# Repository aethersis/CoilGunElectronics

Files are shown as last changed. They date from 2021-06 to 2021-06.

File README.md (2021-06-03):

# CoilGunElectronics
A collection of parts needed to build multistage coil guns. I try to design everything so that it can take up to 600V. Coating solder joints with special insulating varnish is still recommended. The coil gun stages are designed for 400V 470uF or 1000uF capacitors and the traces should be additionally plated with thick layer of solder or a wire should be soldered alongside those traces.

See http://digitalghosts.blog for more details.

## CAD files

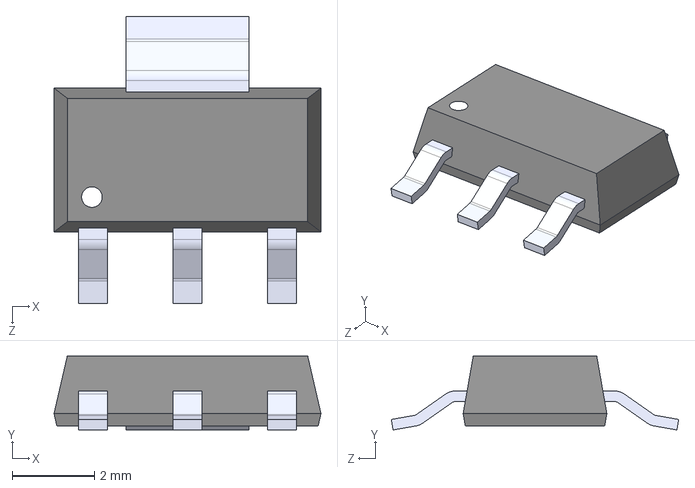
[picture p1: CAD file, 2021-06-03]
coilgun_controller_v1/SOT230P700X180-4N.step
6.50 x 1.80 x 7.00 mm

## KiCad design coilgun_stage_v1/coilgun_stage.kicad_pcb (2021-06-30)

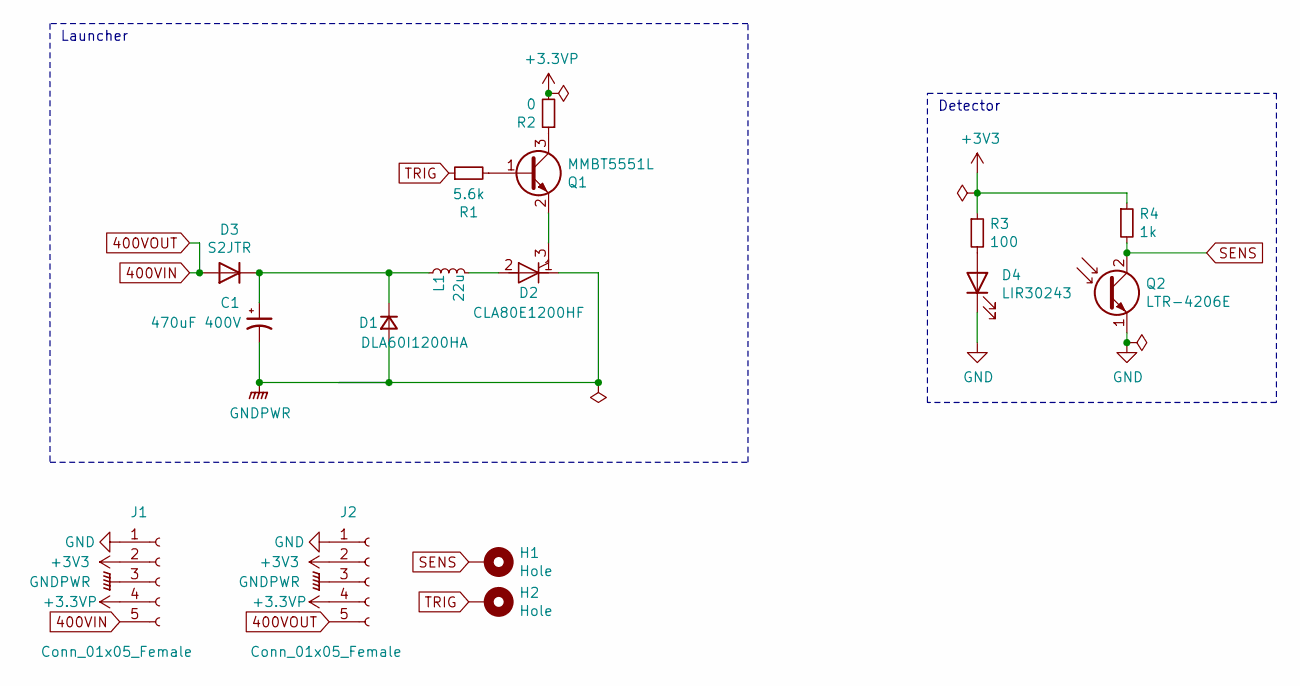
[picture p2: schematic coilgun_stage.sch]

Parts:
C1: 470uF 400V; CP_Radial_D35.0mm_P10.00mm_SnapIn
D1: DLA60I1200HA; TO-247-2_Vertical
D2: CLA80E1200HF; TO-247-3_Vertical
D3: S2JTR; D_SMB
D4: LIR30243; JST_PH_B2B-PH-K_1x02_P2.00mm_Vertical
H1, H2: Hole; PinHeader_1x01_P2.00mm_Vertical
J1, J2: Conn_01x05_Female; PinHeader_1x07_P2.54mm_Horizontal_3_6_missing
L1: 22u; L_Axial_L17.5mm_D12.0mm_P20.32mm_Horizontal_Vishay_IM-10-46
Q1: MMBT5551L; SOT-23
Q2: LTR-4206E; JST_PH_B2B-PH-K_1x02_P2.00mm_Vertical
R1: 5.6k; R_0603_1608Metric_Pad0.98x0.95mm_HandSolder
R2: 0; R_0603_1608Metric_Pad0.98x0.95mm_HandSolder
R3: 100; R_0603_1608Metric_Pad0.98x0.95mm_HandSolder
R4: 1k; R_0603_1608Metric_Pad0.98x0.95mm_HandSolder

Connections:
400VIN: D3.2 (A), J1.5, J2.5
+3.3VP: J1.4, J2.4, R2.2
+3V3: J1.2, J2.2, R3.1, R4.1
GND: D4.1 (K), J1.1, J2.1, Q2.1 (E)
GNDPWR: C1.2, D1.2 (A), D2.1 (K), J1.3, J2.3
unnamed: C1.1, D1.1 (K), D3.1 (K), L1.1
unnamed: D2.2 (A), L1.2
unnamed: D2.3 (G), Q1.2 (E)
unnamed: D4.2 (A), R3.2
unnamed: Q1.1 (B), R1.2
unnamed: Q1.3 (C), R2.1
SENS: H1.1, Q2.2 (C), R4.2
TRIG: H2.1, R1.1

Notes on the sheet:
Detector
Launcher

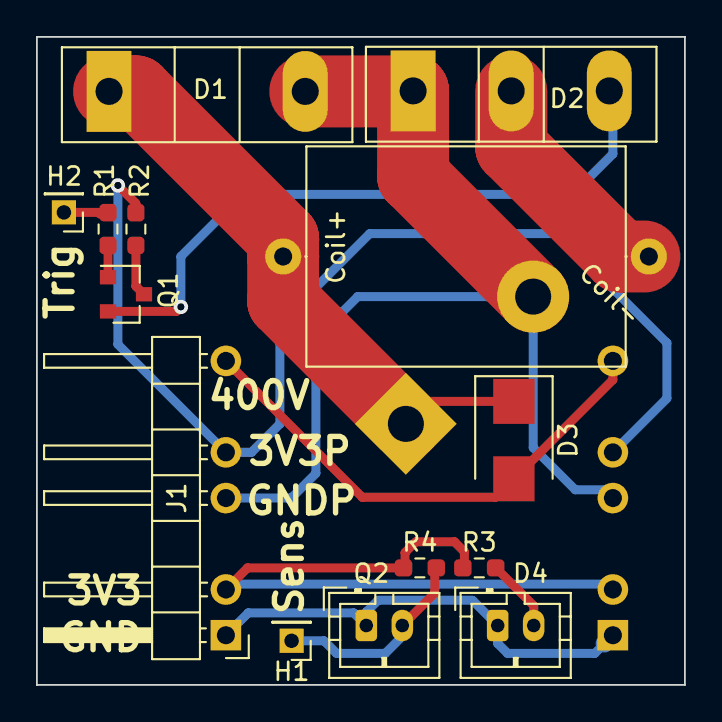
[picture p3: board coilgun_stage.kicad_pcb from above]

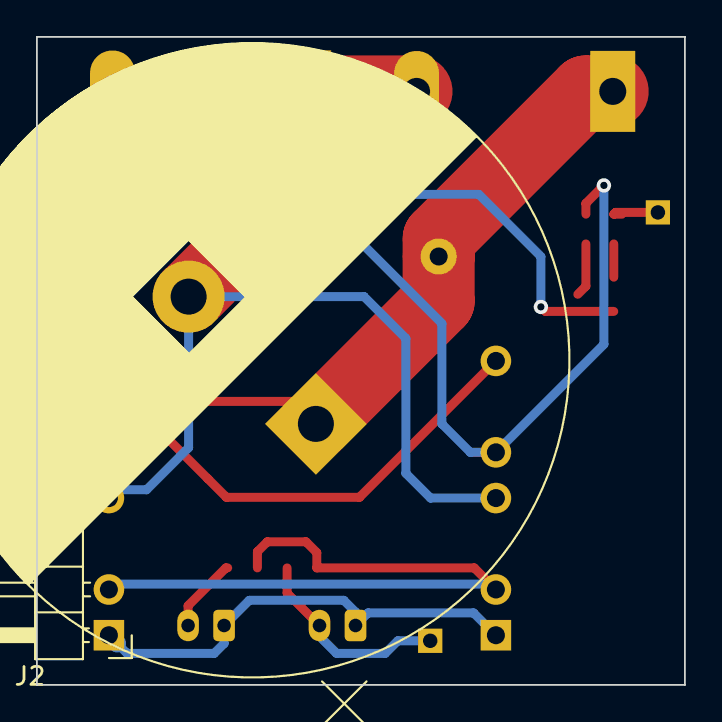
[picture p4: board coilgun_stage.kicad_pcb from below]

Board: 2 copper layers, 36.0 x 36.0 mm, 16 parts (2 on the bottom side), 13 nets.

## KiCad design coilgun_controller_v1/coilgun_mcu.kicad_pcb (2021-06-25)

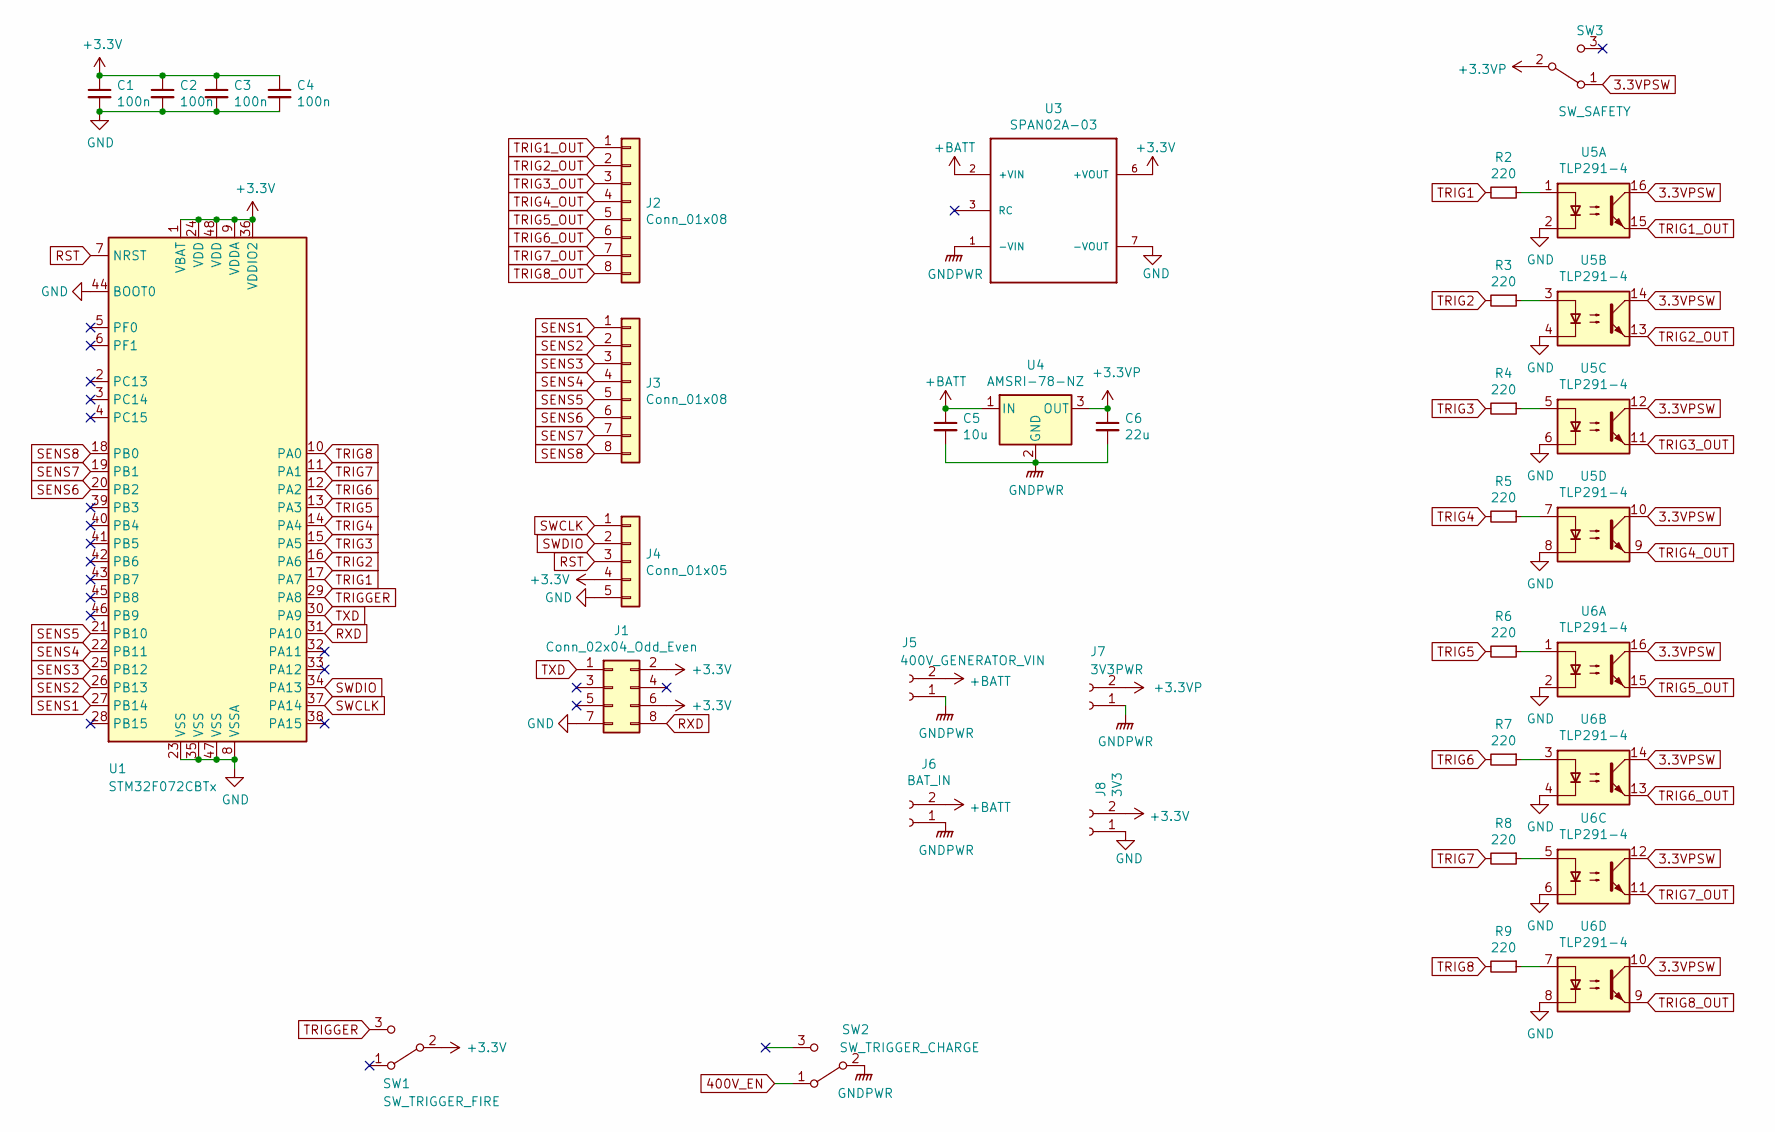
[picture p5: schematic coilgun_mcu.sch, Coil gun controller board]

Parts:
C1, C2, C3, C4: 100n; C_0603_1608Metric_Pad1.08x0.95mm_HandSolder
C5: 10u; C_0805_2012Metric
C6: 22u; C_0805_2012Metric
J1: Conn_02x04_Odd_Even; PinHeader_2x04_P2.54mm_Vertical
J2, J3: Conn_01x08; PinHeader_1x08_P2.54mm_Vertical
J4: Conn_01x05; PinHeader_1x05_P2.54mm_Vertical
J5: 400V_GENERATOR_VIN; PhoenixContact_MCV_1,5_2-G-5.08_1x02_P5.08mm_Vertical
J6: BAT_IN; PhoenixContact_MCV_1,5_2-G-5.08_1x02_P5.08mm_Vertical
J7: 3V3PWR; PinHeader_1x02_P2.54mm_Vertical
J8: 3V3; PinHeader_1x02_P2.54mm_Vertical
R2, R3, R4, R5, R6, R7, R8, R9: 220; R_0603_1608Metric_Pad0.98x0.95mm_HandSolder
SW1: SW_TRIGGER_FIRE; JST_PH_B3B-PH-K_1x03_P2.00mm_Vertical
SW2: SW_TRIGGER_CHARGE; JST_PH_B3B-PH-K_1x03_P2.00mm_Vertical
SW3: SW_SAFETY; JST_PH_B3B-PH-K_1x03_P2.00mm_Vertical
U1: STM32F072CBTx; LQFP-48_7x7mm_P0.5mm
U3: SPAN02A-03; SPAN02; PARTNO 1866-4766-ND
U4: AMSRI-78-NZ; TO-220-3_Vertical
U5, U6: TLP291-4; SOIC-16_4.55x10.3mm_P1.27mm

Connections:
3.3VPSW: SW3.1 (A), U5.10, U5.12, U5.14, U5.16, U6.10, U6.12, U6.14, U6.16
400V_EN: SW2.1 (A)
+3.3VP: C6.1, J7.2, SW3.2 (B), U4.3 (OUT)
+3V3: C1.1, C2.1, C3.1, C4.1, J1.2, J1.6, J4.4, J8.2, SW1.2 (B), U1.1 (VBAT), U1.9 (VDDA), U1.24 (VDD), U1.36 (VDDIO2), U1.48 (VDD), U3.6 (+VOUT)
+BATT: C5.1, J5.2, J6.2, U3.2 (+VIN), U4.1 (IN)
GND: C1.2, C2.2, C3.2, C4.2, J1.7, J4.5, J8.1, U1.8 (VSSA), U1.23 (VSS), U1.35 (VSS), U1.44 (BOOT0), U1.47 (VSS), U3.7 (-VOUT), U5.2, U5.4, U5.6, U5.8, U6.2, U6.4, U6.6, U6.8
GNDPWR: C5.2, C6.2, J5.1, J6.1, J7.1, SW2.2 (B), U3.1 (-VIN), U4.2 (GND)
unnamed: R2.1, U5.1
unnamed: R3.1, U5.3
unnamed: R4.1, U5.5
unnamed: R5.1, U5.7
unnamed: R6.1, U6.1
unnamed: R7.1, U6.3
unnamed: R8.1, U6.5
unnamed: R9.1, U6.7
RST: J4.3, U1.7 (NRST)
RXD: J1.8, U1.31 (PA10)
SENS1: J3.1, U1.27 (PB14)
SENS2: J3.2, U1.26 (PB13)
SENS3: J3.3, U1.25 (PB12)
SENS4: J3.4, U1.22 (PB11)
SENS5: J3.5, U1.21 (PB10)
SENS6: J3.6, U1.20 (PB2)
SENS7: J3.7, U1.19 (PB1)
SENS8: J3.8, U1.18 (PB0)
SWCLK: J4.1, U1.37 (PA14)
SWDIO: J4.2, U1.34 (PA13)
TRIG1: R2.2, U1.17 (PA7)
TRIG1_OUT: J2.1, U5.15
TRIG2: R3.2, U1.16 (PA6)
TRIG2_OUT: J2.2, U5.13
TRIG3: R4.2, U1.15 (PA5)
TRIG3_OUT: J2.3, U5.11
TRIG4: R5.2, U1.14 (PA4)
TRIG4_OUT: J2.4, U5.9
TRIG5: R6.2, U1.13 (PA3)
TRIG5_OUT: J2.5, U6.15
TRIG6: R7.2, U1.12 (PA2)
TRIG6_OUT: J2.6, U6.13
TRIG7: R8.2, U1.11 (PA1)
TRIG7_OUT: J2.7, U6.11
TRIG8: R9.2, U1.10 (PA0)
TRIG8_OUT: J2.8, U6.9
TRIGGER: SW1.3 (C), U1.29 (PA8)
TXD: J1.1, U1.30 (PA9)

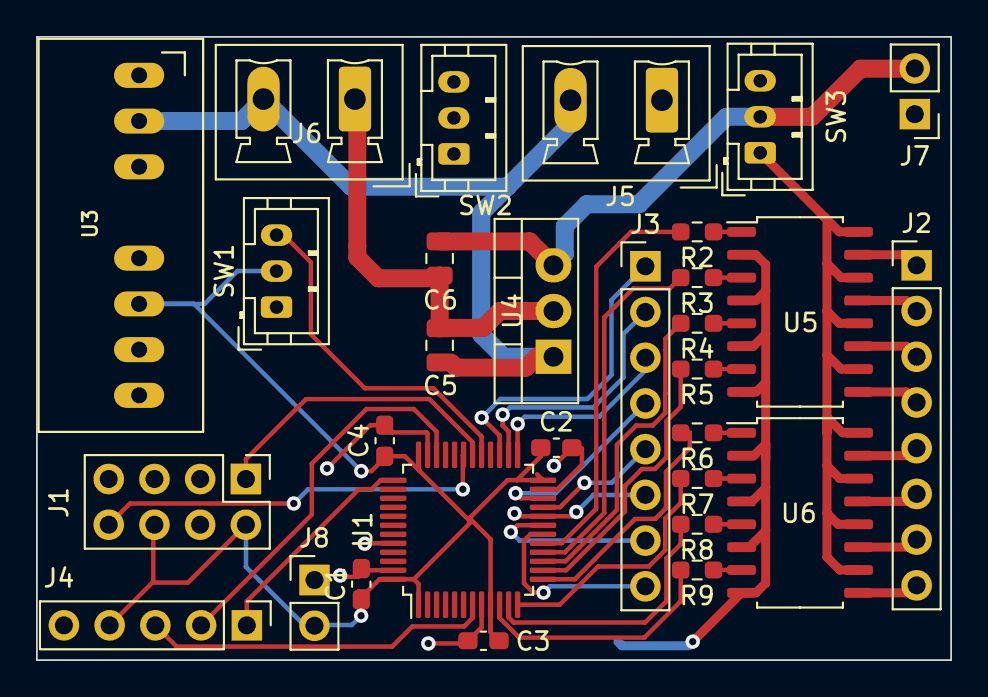
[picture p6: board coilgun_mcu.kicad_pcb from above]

Board: 2 copper layers, 50.8 x 34.6 mm, 30 parts (0 on the bottom side), 44 nets.

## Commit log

2021-06-03 Add the electronics for the first revision
    [SOT230P700X180-4N.step, coilgun_mcu.kicad_pcb, coilgun_mcu.sch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]
2021-06-05 Increase track clearance, cosmetic fixes
    [coilgun_mcu.kicad_pcb, coilgun_mcu.sch, coilgun_stage.kicad_pcb]
2021-06-25 Get rid of the useless optocoupler
    [coilgun_mcu.kicad_pcb, coilgun_mcu.sch, coilgun_stage.kicad_pcb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]
2021-06-30 Fix swapped labels
    [coilgun_stage.kicad_pcb]
